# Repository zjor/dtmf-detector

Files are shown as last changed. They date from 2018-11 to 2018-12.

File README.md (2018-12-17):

# DTFM Detector

## Overview

The device captures input from the microphone and decodes digit encoded using DTFM.

## Schematic

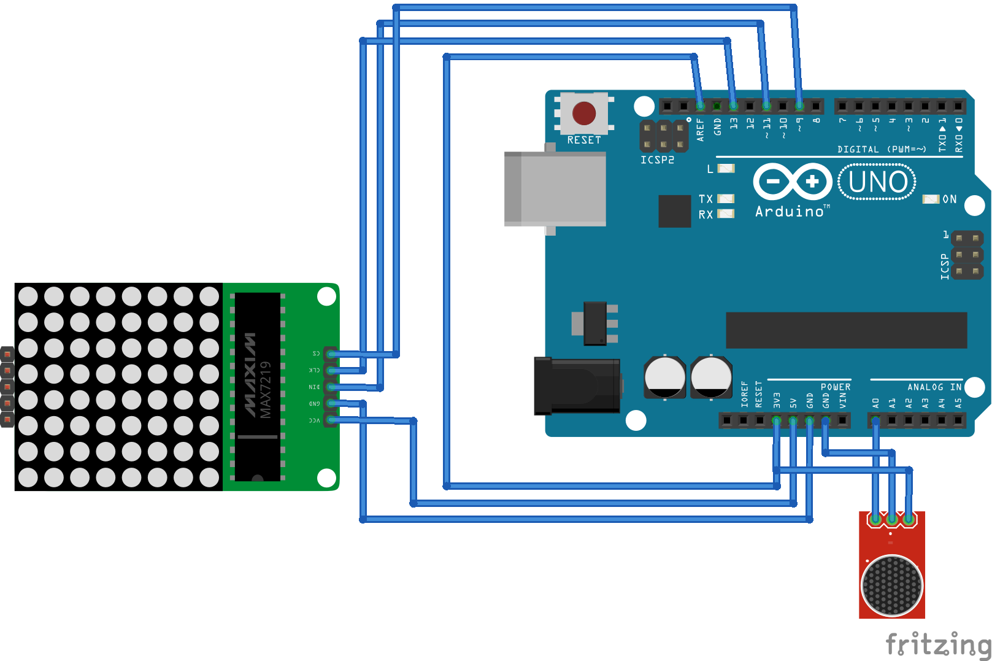
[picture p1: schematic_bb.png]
schematic


## Connections

### Display to Arduino

|Display|Arduino|
|---|---|
|VCC |5V |
|GND |GND |
|DIN |D11 |
|CLK |D13 |
|CS |D9 |

### Mic to Arduino

|Mic |Arduino|
|---|---|
|VCC |3.3V |
|GND |GND |
|Out |A0 |

Note: Connect 3.3V to AREF

## Video

video (https://www.youtube.com/watch?v=vfhiGLL-tyk)

## How to build

Run `gradlew fatJar` from processing folder

## Capturing serial output to file
1. `script -a -t0 serial.txt`
2. `screen -L /dev/tty.usbXXXXX <bauds>`
3. Stop screen: Ctrl+A + Ctrl+K
4. Stop script: Ctrl+D

## References

- [DTFM tone generator](http://onlinetonegenerator.com/dtmf.html)
- http://www.hex705.com/logging-serial-communication-to-a-text-file-arduino-and-osx/
- [Goertzel algorithm description](http://ru.dsplib.org/content/goertzel/goertzel.html)
- https://xantorohara.github.io/led-matrix-editor

- [habr](https://habr.com/post/432498/)

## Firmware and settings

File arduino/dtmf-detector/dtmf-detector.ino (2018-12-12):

/**
 * Connections:
 * [ Mic to Arduino ]
 *  - Out -> A0
 *  - Vcc -> 3.3V
 *  - Gnd -> Gnd
 *  - Arduino: AREF -> 3.3V
 * [ Display to Arduino ]
 *  - Vcc -> 5V
 *  - Gnd -> Gnd
 *  - DIN -> D11
 *  - CLK -> D13
 *  - CS  -> D9
 */
#include <binary.h>
#include <avr/pgmspace.h>

#include <LEDMatrixDriver.hpp>

#define CS_PIN      9

#define N           256
#define IX_LEN      8
#define THRESHOLD   20

LEDMatrixDriver lmd(1, CS_PIN);

uint8_t samples[N];
volatile uint16_t samplePos = 0;

float spectrum[IX_LEN];

// Frequences [697.0, 770.0, 852.0, 941.0, 1209.0, 1336.0, 1477.0, 1633.0]
// Calculated for 9615Hz 256 samples  
const float cos_t[IX_LEN] PROGMEM = {
  0.8932243011955153, 0.8700869911087115, 0.8448535652497071, 0.8032075314806449, 
  0.6895405447370669, 0.6343932841636456, 0.5555702330196023, 0.4713967368259978
  };
  
const float sin_t[IX_LEN] PROGMEM = {
  0.44961132965460654, 0.49289819222978404, 0.5349976198870972, 0.5956993044924334, 
  0.7242470829514669, 0.7730104533627369, 0.8314696123025451, 0.8819212643483549
  };

typedef struct {
  char digit;
  uint8_t index;   
} digit_t;

digit_t detected_digit;

const char table[4][4] PROGMEM = {
  {'1', '2', '3', 'A'},
  {'4', '5', '6', 'B'},
  {'7', '8', '9', 'C'},
  {'*', '0', '#', 'D'}
};

const uint8_t char_indexes[4][4] PROGMEM = {
  {1, 2, 3, 10},
  {4, 5, 6, 11},
  {7, 8, 9, 12},
  {15, 0, 14, 13}
};

byte font[16][8] = { 
                     {0x00,0x38,0x44,0x4c,0x54,0x64,0x44,0x38}, // 0
                     {0x04,0x0c,0x14,0x24,0x04,0x04,0x04,0x04}, // 1
                     {0x00,0x30,0x48,0x04,0x04,0x38,0x40,0x7c}, // 2
                     {0x00,0x38,0x04,0x04,0x18,0x04,0x44,0x38}, // 3
                     {0x00,0x04,0x0c,0x14,0x24,0x7e,0x04,0x04}, // 4
                     {0x00,0x7c,0x40,0x40,0x78,0x04,0x04,0x38}, // 5
                     {0x00,0x38,0x40,0x40,0x78,0x44,0x44,0x38}, // 6
                     {0x00,0x7c,0x04,0x04,0x08,0x08,0x10,0x10}, // 7
                     {0x00,0x3c,0x44,0x44,0x38,0x44,0x44,0x78}, // 8
                     {0x00,0x38,0x44,0x44,0x3c,0x04,0x04,0x78}, // 9
                     {0x00,0x1c,0x22,0x42,0x42,0x7e,0x42,0x42}, // A
                     {0x00,0x78,0x44,0x44,0x78,0x44,0x44,0x7c}, // B
                     {0x00,0x3c,0x44,0x40,0x40,0x40,0x44,0x7c}, // C
                     {0x00,0x7c,0x42,0x42,0x42,0x42,0x44,0x78}, // D
                     {0x00,0x0a,0x7f,0x14,0x28,0xfe,0x50,0x00}, // #
                     {0x00,0x10,0x54,0x38,0x10,0x38,0x54,0x10}  // *
                  };

void initADC() {
  // Init ADC; f = ( 16MHz/prescaler ) / 13 cycles/conversion 
  ADMUX  = 0; // Channel sel, right-adj, use AREF pin
  ADCSRA = _BV(ADEN)  | // ADC enable
           _BV(ADSC)  | // ADC start
           _BV(ADATE) | // Auto trigger
           _BV(ADIE)  | // Interrupt enable
           _BV(ADPS2) | _BV(ADPS1) | _BV(ADPS0); // 128:1 / 13 = 9615 Hz
  ADCSRB = 0; // Free-run mode
  DIDR0  = _BV(0); // Turn off digital input for ADC pin      
  TIMSK0 = 0;                // Timer0 off
}

void goertzel(uint8_t *samples, float *spectrum) {
  float v_0, v_1, v_2;
  float re, im, amp;
    
  for (uint8_t k = 0; k < IX_LEN; k++) {
    float c = pgm_read_float(&(cos_t[k]));
    float s = pgm_read_float(&(sin_t[k]));
    
    float a = 2. * c;
    v_0 = v_1 = v_2 = 0;  
    for (uint16_t i = 0; i < N; i++) {
      v_0 = v_1;
      v_1 = v_2;
      v_2 = (float)(samples[i]) + a * v_1 - v_0;
    }
    re = c * v_2 - v_1;
    im = s * v_2;
    amp = sqrt(re * re + im * im);
    spectrum[k] = amp;        
  } 
}

float avg(float *a, uint16_t len) {
  float result = .0;
  for (uint16_t i = 0; i < len; i++) {
    result += a[i];
  }
  return result / len;
}

int8_t get_single_index_above_threshold(float *a, uint16_t len, float threshold) {
  
  if (threshold < THRESHOLD) {
    return -1;
  }
  
  int8_t ix = -1;
  for (uint16_t i = 0; i < len; i++) {
    if (a[i] > threshold) {
      if (ix == -1) {
        ix = i;
      } else {
        return -1;
      }
    } 
  }
  return ix;  
}

void detect_digit(float *spectrum) {
  float avg_row = avg(spectrum, 4);
  float avg_col = avg(&spectrum[4], 4);
  int8_t row = get_single_index_above_threshold(spectrum, 4, avg_row);
  int8_t col = get_single_index_above_threshold(&spectrum[4], 4, avg_col);
  
  if (row != -1 && col != -1 && avg_col > 200) {
    detected_digit.digit = pgm_read_byte(&(table[row][col]));
    detected_digit.index = pgm_read_byte(&(char_indexes[row][col]));
  } else {
    detected_digit.digit = 0;
  }
}

void drawSprite(byte* sprite) {
  // The mask is used to get the column bit from the sprite row
  byte mask = B10000000;
  
  for(int iy = 0; iy < 8; iy++ ) {
    for(int ix = 0; ix < 8; ix++ ) {
      lmd.setPixel(7 - iy, ix, (bool)(sprite[iy] & mask ));

      // shift the mask by one pixel to the right
      mask = mask >> 1;
    }

    // reset column mask
    mask = B10000000;
  }
}

void setup() {  
  cli();
  initADC();
  sei();

  Serial.begin(115200);
  
  lmd.setEnabled(true);
  lmd.setIntensity(2);
  lmd.clear();
  lmd.display();

  detected_digit.digit = 0;
}

unsigned long z = 0;

void loop() {
  while(ADCSRA & _BV(ADIE)); // Wait for audio sampling to finish
  goertzel(samples, spectrum);  
  detect_digit(spectrum);

  if (detected_digit.digit != 0) {
    drawSprite(font[detected_digit.index]);
    lmd.display();
  }   
  
  if (z % 5 == 0) {    
    for (int i = 0; i < IX_LEN; i++) {
      Serial.print(spectrum[i]);
      Serial.print("\t");
    }
    Serial.println();    
    Serial.println((int)detected_digit.digit);
  }
  z++;

  samplePos = 0;

  ADCSRA |= _BV(ADIE);       // Resume sampling interrupt
}

ISR(ADC_vect) { 
  uint16_t sample = ADC;

  samples[samplePos++] = sample - 400;
  
  if(samplePos >= N) {
    ADCSRA &= ~_BV(ADIE); // Buffer full, interrupt off
  }
}

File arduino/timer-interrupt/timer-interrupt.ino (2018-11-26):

const int led_pin = PB5;

const uint16_t t1_load = 0;
const uint16_t t1_comp = 31250;

void setup() {
  cli();
  
  DDRB |= (1 << led_pin);
  initTimer();
  
  sei();
}

void loop() {  
  delay(500);
}

void initTimer() {
  // Reset Timer1 Control Reg A
  TCCR1A = 0;

// Set CTC mode
  TCCR1B &= ~(1 << WGM13);
  TCCR1B |= (1 << WGM12);

// Set prescaler to 256
  TCCR1B |= (1 << CS12);
  TCCR1B &= ~(1 << CS11);
  TCCR1B &= ~(1 << CS10);
  
// Reset Timer 1 and set compare value
  TCNT1 = t1_load;
  OCR1A = t1_comp;

// Enable Timer 1 compare interrupt
  TIMSK1 = (1 << OCIE1A);
}

ISR (TIMER1_COMPA_vect) {
  PORTB ^= (1 << led_pin);
}

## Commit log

2018-11-18 detecting digit from data from arduino
2018-11-26 timer interrupt sketch
2018-11-26 running ADC at 1Hz at interrupt mode
2018-11-27 debugging signal at 8kHz 205 samples
2018-11-27 debugging on arduino
2018-12-12 schematic added
    [schematic.fzz]
